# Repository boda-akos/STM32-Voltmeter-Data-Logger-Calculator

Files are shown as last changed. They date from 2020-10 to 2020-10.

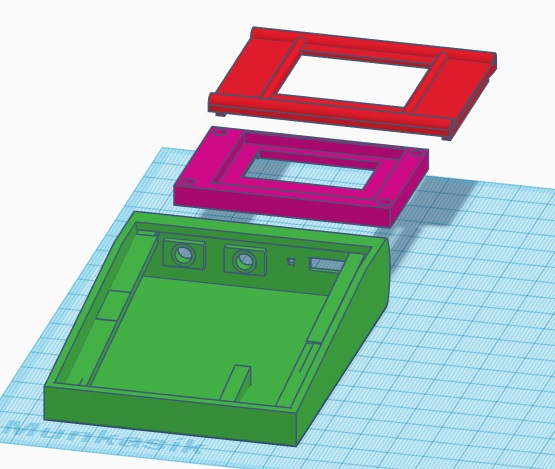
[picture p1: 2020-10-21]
3D_Parts.jpg

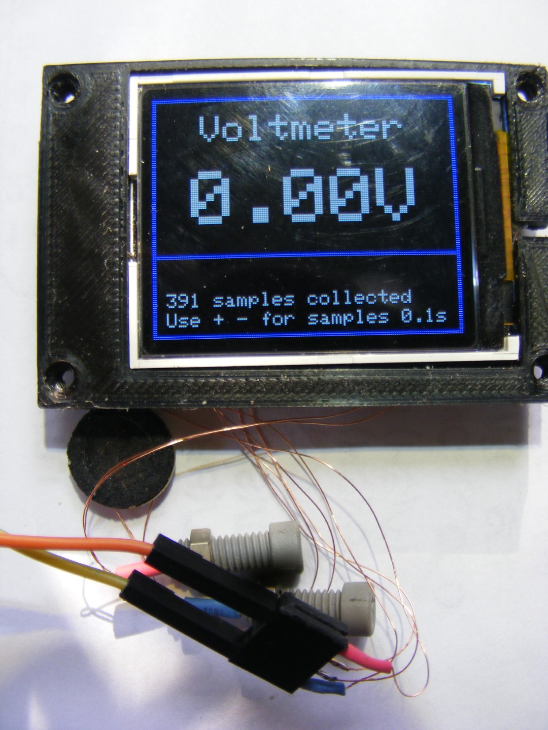
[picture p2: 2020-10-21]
DSCF2553 (Nagy).JPG

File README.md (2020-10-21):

# STM32-Voltmeter-Data-Logger-Calculator
Arduino STM32 based instrument. Voltmeter, continuity beeper, curve tracer, data logger, calculator hex and decimal.

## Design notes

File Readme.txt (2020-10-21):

Description :

This instrument has some useful functions for Arduino users. Besides being a 
voltmeter with data logging, it could answer questions like "how much voltage 
falls on the LED at 10mA current?" or "is this an IR LED or what?" by
showing the diode's voltage drop as a function of current at 5 points. It has
a beeper for continuity check as well as for logic level testing, without the 
need to look at the display. Furthermore, it can play 3 octaves "musical pitch"
as a function of voltage, which could be useful when the question arises
"is there 5V, 12V, or nothing?"  but you have to keep your eyes on the PCB.

Hex calculator 32 bits has the basic integer arithmetic functions plus AND. 
Entered hex numbers are shown at the same time in decimal in smaller numbers. 
This can be reversed so that the input is decimal and the result is decimal too
and the hex numbers are smaller.   
Operates 10-20 hours with one battery charge.

Functions : 

1. 12-bit resolution voltmeter 0-31V auto-ranging 0-3V 0-31V
   Input impedance 11.2 Mohm or more. Accuracy depends on some factors, about 1%.
    Specials : 
     - Data logging at 100ms or 1 sec intervals, max. 3600 FP data.
     - 3 octave pitch to estimate voltage without looking
     - Beep function to test logic level without looking
2. Continuity tester (1mA current)
3. Curve draw for diodes 0.1-0.3-1-3-10 mA current 0-3V voltage
4. Hex calculator, only integers, + - / * & (AND) function.
   Shows operators and results in decimal at the same time.
5. Decimal calculator, only integers. Shows HEX results as well.

Power : Li-Ion battery with USB charger.  
Dimensions : approx. 70x100x25mm.

Main parts : 
STM32 Blue Pill board 
ST7735 SPI 1.77" LCD
Micro USB Li-Ion charger PCB
Phone battery 700mAh or more
16x 6mm switch array 2 pcs 
2mm banana sockets
Off-On-On slider switch
Small (really small SMD) electronic parts
Source : Aliexpress

Circuit description : The battery is charged from micro USB by the TC4056A board. 
Voltage is fed to power switch, the 2 ON position of the switch selects calculator
or voltmeter functions. The STM32 board's regulator provides 3.3V from the battery 
3.6-4.2V. The 3.3V supply is also the reference voltage for the STM32 A/D converter.
Its value determines the accuracy, so it should be measured and entered in the code.
(float vref=3.3;  means 3.30V , enter your value if different by 1% or more) 

1. Calculator : the STM32 scans the keyboard, decodes the keys and responds to it. 
The 0-F keys work in HEX input mode, the 0-9 keys in decimal mode. & key selects 
between hex or decimal mode, C key deletes the last entry, = key shows result. 

2A. Voltmeter : This function is selected by the = key, default by start.
The instrument shows 0 for negative input voltages, but no damage is done.
The useful range is limited to approx. 31VDC. The data (3600 floating point Volts)
is stored in RAM at 1 or 0.1s intervals. 
Key functions:
 =   toggles 0.1 sec - 1 sec sample interval.
               /   turns on octave pitch. Low C 131Hz at 0V, the range is divided in 21 steps
                     so the max value corresponds to C 1044Hz 3 octaves higher.
               *   turns on logic check. Low logic level : no sound, high >0.9V level 784Hz.
               C   turns off sound 
               -   resets data log counter, fresh data starts from index = 0. 
               +   Enter data log mode, shows 50 data log, starting with recent voltage samples. 

                     In data log mode 
                                   + advances 50 samples. 
                                   - steps back 50 samples (older data).
                                   = returns to voltmeter mode, data collect resumes. 
                     Data index is shown so the user can determine when the data was collected.
                     Data collection is halted in this mode.
                
2B. Continuity tester : This function is selected by the & key.
The instrument outputs 1mA current and measures the voltage on its input. If the input < 100mV 
the beeper is activated. Higher input voltage does no harm, voltage is measured correctly.

2C. Diode curve draw : This function is selected by the # key.
Current is output in 5 logarithmic steps 0.1, 0.3, 1, 3, 10mA and the resulting input voltage 
is displayed on a graph. The values are displayed in table form too. A resistor will obviously
return a similar logarithmic voltage graph, but a diode's graph is almost linear.
Some typical values in attachment. 

Analog circuit : is built on a perfboard 45x10mm. For connections 0.25mm enamel wire is used.
The HT7333 regulator replaces the built-in RT8183-B, or AMS1117. 
The circuit is  a low-res logarithmic D/A converter driving the current output. The current 
source has 5 resistors from which 4 are switched on by Mosfets. 
The current through the resistors drives the BCV62 current mirror, the common base  is fed to PA2,
which can disable the current mirror by pulling this point high, or could measure its voltage 
to calculate the exact current flowing through the resistors. The current mirror's output is 
separated by a diode from the voltmeter input as protection against high positive voltages.

The voltage divider 10M/1.2M is connected to PA1 while a direct input is to PA0. Both are 
protected by resistors and diode network. A 100nF capacitor filters the input noise. Take care
to use this ground point for the input ground, and feed it separately to the STM32 board to 
avoid ground loop issues.
The board has a speaker driver, the 150ohm resistor controls the volume. 

Switch array : ready made 4x4 switch arrays, one cut in half. The 4 "horizontal" scan lines
are parallel connected and fed to PB9,PB6,PB4,PC13 and the 6 "vertical" scan lines are driven
by PB8,PB7,PB5,PB3,PA14,PA15. 

LCD :  1.77” LCD has FPC 14 connection.  I soldered  0.25mm enamel wire on the connector without
 difficulties.  Backlight  supply  3.3V serial 10 ohm resistor, current 35 mA.   
----------------------------------------------------------------------------
Do not attempt to measure AC voltage with this instrument, keep away from mains in particular !!

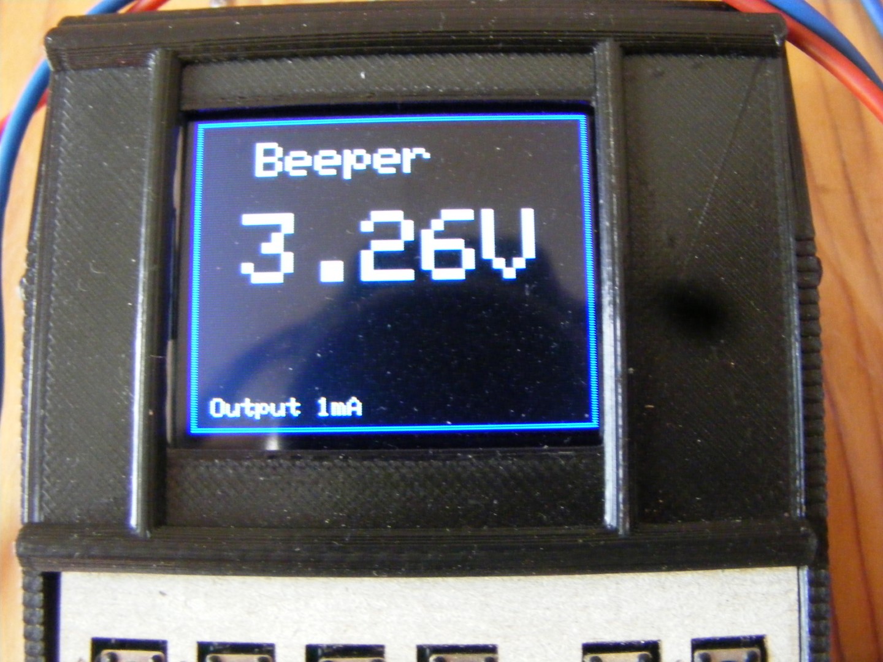
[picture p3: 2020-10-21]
DSCF2561 (Nagy).JPG

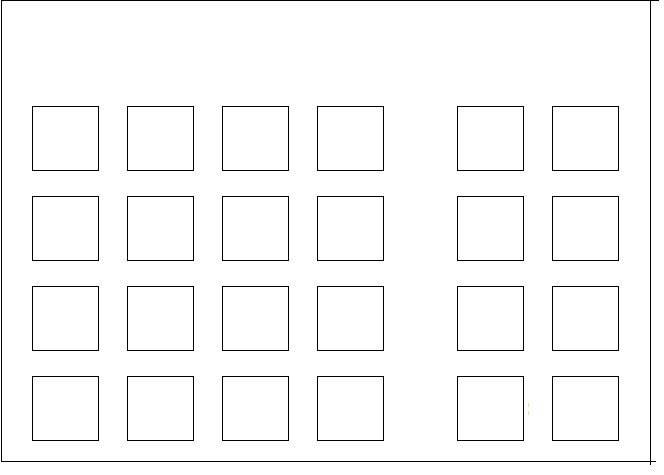
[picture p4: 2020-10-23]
hexCalcCut1.png

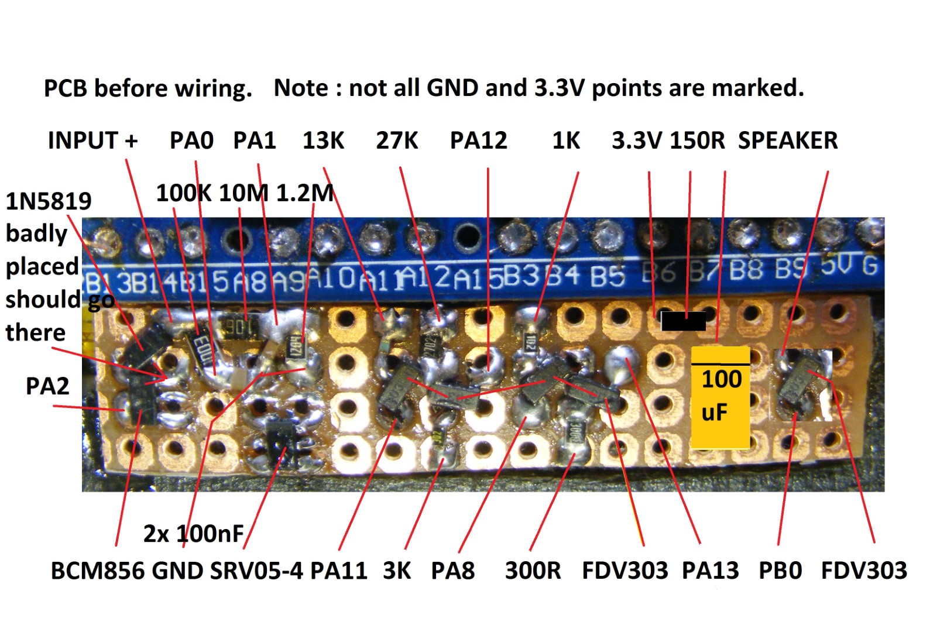
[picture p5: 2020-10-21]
PCB (Nagy).jpg

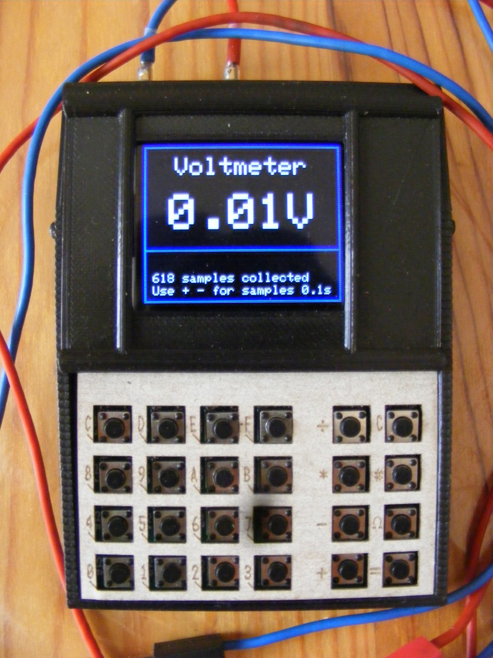
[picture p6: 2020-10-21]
DSCF2554 (Nagy).JPG

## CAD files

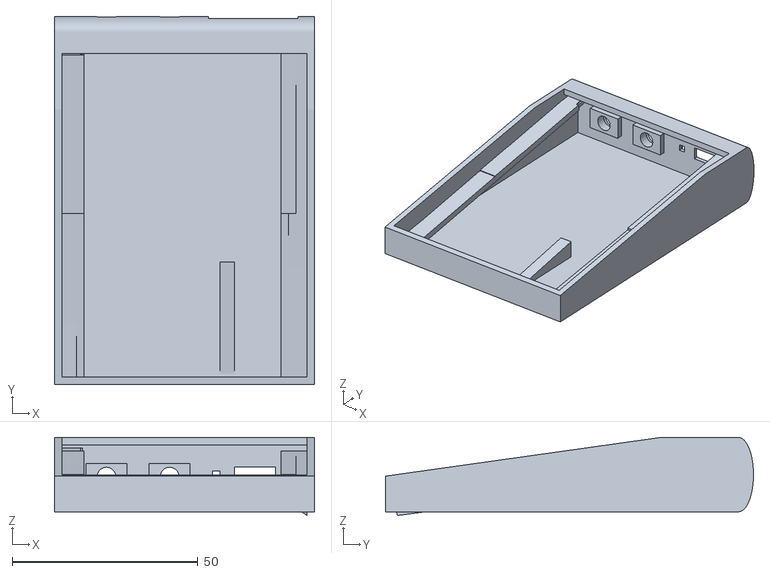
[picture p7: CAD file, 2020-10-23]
HexCalcBase.stl
70.0 x 99.0 x 21.0

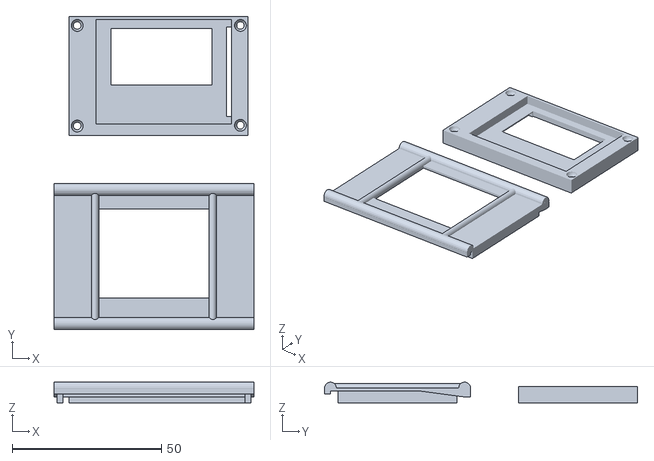
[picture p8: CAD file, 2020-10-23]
HexCalcTop.stl
67.0 x 105.0 x 7.00

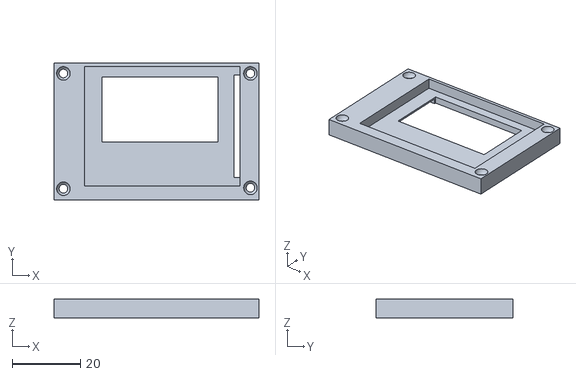
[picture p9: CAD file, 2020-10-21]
Frame.stl
60.0 x 40.0 x 5.50

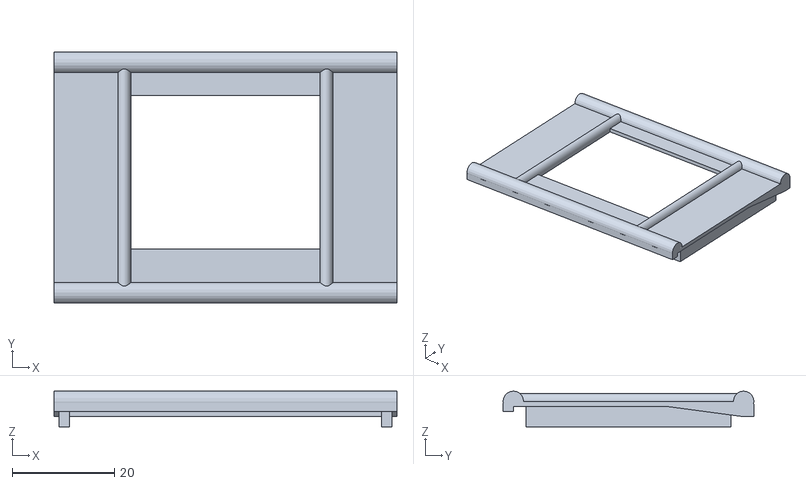
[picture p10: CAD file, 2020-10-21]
Top.stl
67.0 x 49.0 x 7.00

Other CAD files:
Base.stl

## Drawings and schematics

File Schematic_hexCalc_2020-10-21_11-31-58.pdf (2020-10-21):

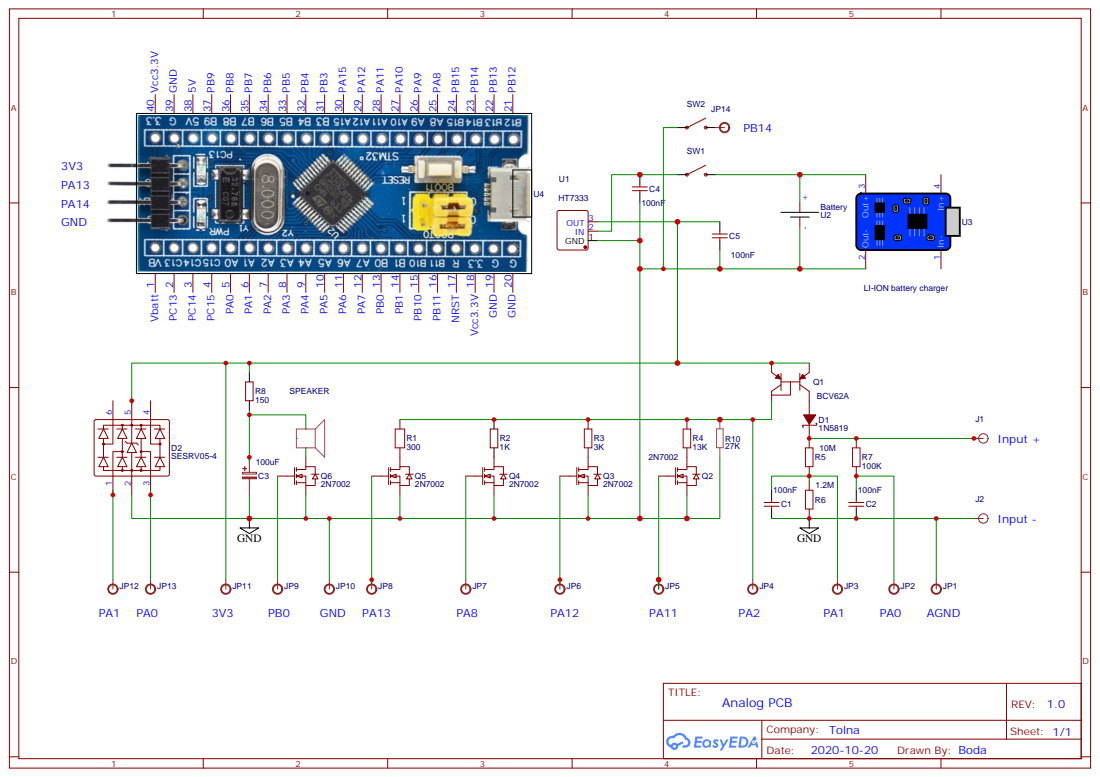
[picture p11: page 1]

LI-ION battery charger

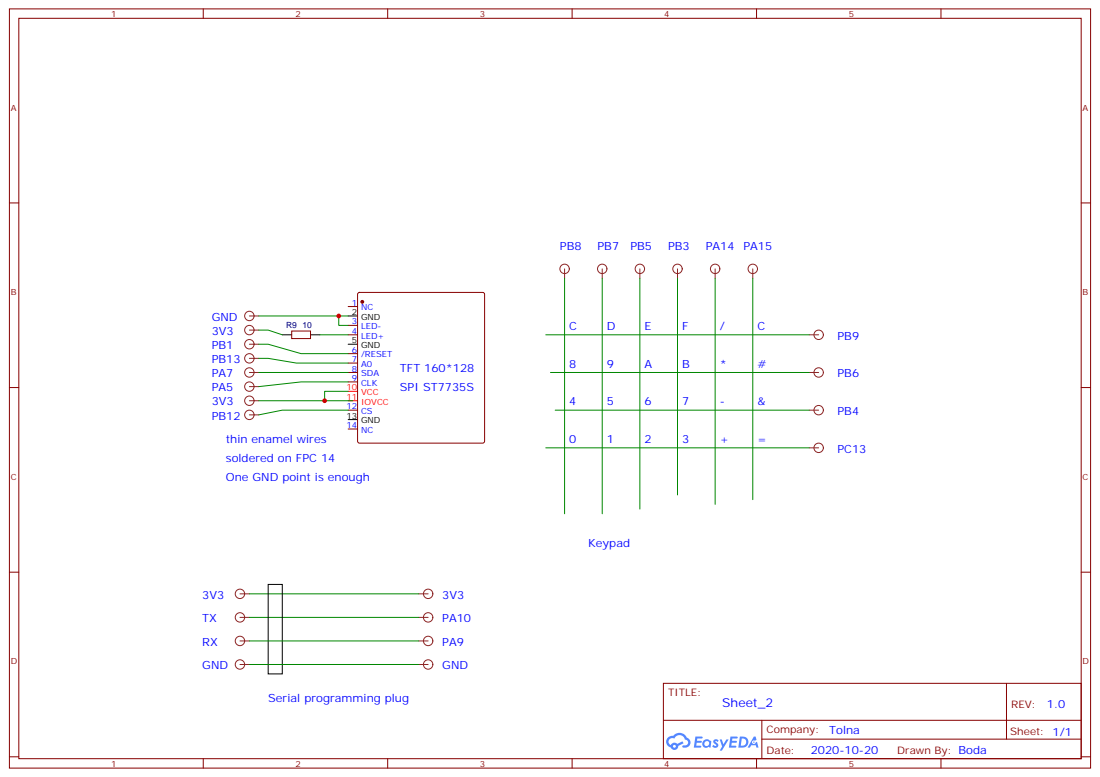
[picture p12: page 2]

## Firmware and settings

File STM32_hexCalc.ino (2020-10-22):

//STM32F103CBT6 (china copy GD103) ST7735 14 pin SPI 1.77" 
//PA0 0-3300mV 100k series, 100nF to GND. PA1 divider 10M / 1M2, 100nF to GND 
//PA2 connected to current mirror common base. when input, samples the ref V on resistors. When high output, disables the current mirror.
//100uA flows always (27.4k). PA11 200uA,PA12 900uA,PA8 2.9mA,PA13 9.9mA via mosfets
//PB14 senses power switch position

#include <Adafruit_GFX.h>  
#include <Adafruit_ST7735.h> 
#include <SPI.h>

#define TFT_CS     PB12
#define TFT_DC     PB13
#define TFT_RST    PC14 

Adafruit_ST7735 tft = Adafruit_ST7735(TFT_CS, TFT_DC, TFT_RST);

byte kdrv[]={PB8,PB7,PB5,PB3,PA14,PA15};
byte kbin[]={PB9,PB6,PB4,PC13};
byte uasw[]={PA11,PA12,PA8,PA13};
byte kbcod[]={12,8,4,0,13,9,5,1,14,10,6,2,15,11,7,3,'/','*','-','+','C','&','#','='};
float sample[3600],prev[8],vref=3.300,m ;   //vref is the 3.3V supply HT7333 measured w Fluke12;
unsigned int tim1,tim2,tim3,tim4=100,timout=6000;
byte scn=0xff, stat ,opr, hexopr=1,dvm =0; String txt[]={"DEC","HEX"};
String mA[]={"0.1m","0.3m","1.0m","3.0m","10mA"};
unsigned int op[2],num,sidx,tidx,nidx; // sample , tft index 

int fr, freq[]={261,293,330,349,392,440,494}; //261,277,293,311,330,349,367,392,415,440,466,494}; //c c# d d# e f f# g g# a a# b c c# d d# e f f# g g# a a# b
byte x;
void setup(void) {
  disableDebugPorts();
  Serial.begin(9600);
  tft.initR(INITR_BLACKTAB); 
  tft.setRotation(1);
  tft.setTextColor(ST7735_WHITE,ST7735_BLACK);
  for (byte i=0; i<6; i++) pinMode(kdrv[i],OUTPUT); 
  for (byte i=0; i<4; i++) pinMode(kbin[i],INPUT_PULLUP);
  pinMode(PB14,INPUT_PULLUP);  //power switch position
  for (byte i=0; i<4; i++) pinMode(uasw[i],OUTPUT);
  pinMode(PA2,OUTPUT); digitalWrite(PA2,HIGH);tft.fillScreen(ST7735_BLACK); 
  pinMode(PA0, INPUT_ANALOG); pinMode(PA1, INPUT_ANALOG);
  
  //tft.fillScreen(ST7735_BLACK); 
    Timer4.setPeriod(32000); Timer4.setPrescaleFactor(100);
    Timer4.setMode(TIMER_CH1,TIMER_OUTPUTCOMPARE);
    Timer4.setCompare(TIMER_CH1, 1); 
    Timer4.attachInterrupt(TIMER_CH1,handler);
    Timer4.refresh();
    //Timer4.resume();
    Timer4.pause();
    //pinMode(PA9, OUTPUT);
  pinMode(PB0, PWM);  //sound output Timer3
  Timer3.setPrescaleFactor(1000);    //72Mhz divider 
  Timer3.pause(); if (digitalRead(PB14)) dvmFrame(61); else calFrame(); 
}

void loop() {
  if (digitalRead(PB14) !=dvm) {if ( digitalRead(PB14))dvmFrame(61); else calFrame(); };
dvm=digitalRead(PB14);
if (dvm) {                 // stat 0x00-0x0f dvm ; 0x10-0x1f beeper ; 0x20-0x2f scanner
if (scn !=0xff) { byte r=kbcod[scan()]; 
                     
                    if (r==61) {dvmFrame(r);stat = 0x00; if (tim4 == 100) tim4=1000; else tim4=100; } //voltmeter
                    if (r==35) {dvmFrame(r);stat = 0x10;} //beeper
                    if (r==38) {dvmFrame(r);stat = 0x20;} //scanner
                    if (r==42) {stat |= 0x02; stat &=~0x04; Timer3.resume(); tim1 = millis()+timout;} //sound on logic
                    if (r==47) {stat |= 0x04; stat &=~0x02; Timer3.resume(); tim1 = millis()+timout;} //sound on offset
                    if (r==67) {stat &= ~0x06; Timer3.pause();} //sound off
                    if (r=='+') {if (stat&0x08) {stat &= ~0x08;tft.setCursor(8,90); tft.fillRect(7,90,115,30,ST7735_BLACK);}
                                else stat |= 0x08; nidx=sidx;}
                    if (r=='-') {sidx =0; }
                    
                    while(scan() != 0xff); }

                      
if ((stat & 0xf0) == 0x00) { //============================ Voltmeter ================================
 
   pinMode(PA2,OUTPUT); digitalWrite(PA2,HIGH); tft.setCursor(10,45); m= analogRead(PA0);
  if (m>4090) {stat |=0x01; tim2=millis()+timout;} else if (millis()> tim2) stat &= ~0x01;
  if (tim2>millis()) {m=analogRead(PA1); m *= 11.2; m /=1.2;} 
  m*= vref; m/=4095; tft.setCursor(20,40);tft.setTextSize(4); tft.print(m); tft.print('V'); 
  tft.drawLine(2,85,157,85,ST7735_BLUE);tft.drawLine(2,84,157,84,ST7735_BLUE);
  tft.setCursor(8,94); tft.setTextSize(1);
  if (stat & 0x04) tft.print("Sound on    "); else 
  if (stat & 0x02) tft.print("Sound > 0.9V"); else 
  if (!(stat & 0x06)) tft.print("            ");
  tft.setCursor(7,104); tft.print(sidx); tft.print(" samples collected   ");
  tft.setCursor(7,114); tft.print("Use + - for samples ");
  tft.print((float)tim4/1000,1);tft.print('s');//tft.print(stat);
  if (stat & 0x06) sound(); if (millis()>tim1) { Timer3.pause(); }
  if (m>0.2 && stat&0x06) {tim1  = millis()+ timout; Timer3.resume();}  //cycle = 31ms
  if (millis() > tim3) {tim3= tim4 * ((millis()/tim4)+1); //=======================tim4 loop 100ms,1s
  if (stat & 0x08) { 
  dvmFrame('+'); tft.print((float)tim4/1000,1); tft.print(" sec");
  while  (scan() != 23  ) { //wait for = sign
  if (nidx<50) nidx=50; tft.setCursor(6,22);
  for (byte i=50; i; i--) {tft.print(sample[nidx-i]); if ((i%5)==1) tft.println(); tft.print(' ');}
  tft.drawLine(0,0,0,120,ST7735_BLUE);tft.drawLine(1,0,1,120,ST7735_BLUE);
  tft.setCursor(6,115); tft.print("Samples "); tft.print(nidx-50); tft.print(" to ");tft.print(nidx-1); tft.print("   ");
     //while(scan() != 18 && scan() !=19) {if (scan() == 23) break;}
  while(scan() != 18 && scan() !=19 && scan() !=23 );  //react to + - = only
  if (scan() ==18 && nidx>50) nidx -=50;  if (scan() == 19 ) nidx +=50; if (nidx > 3600) nidx=3600;
   
  } //show table inner loop
  } //Table show exit, 0x08 flag reset when calling voltmeter menu
  
  sample[sidx]=m; sidx++; 
  if (sidx > 3599) sidx=0;
  }  //tim4 loop 100ms,1s  //Serial.println(millis()-tim2); Serial.print(' '); tim2=millis();
  }
  
if ((stat & 0xf0) == 0x10) { //=========================== Beeper ====================================
       float m; pinMode(PA2,INPUT); digitalWrite(PA12,1); 
       if (analogRead(0)> 4090) {m= analogRead(PA1); m *= 11.2; m /=1.2;} else m= analogRead(PA0); 
       m*= vref; m/=4095; 
       tft.setCursor(20,40);tft.setTextSize(4); tft.print(m); tft.print('V');
       if ( m < 0.1 ) {Timer3.resume(); sound();} else Timer3.pause(); 
       
  }
                     
if ((stat & 0xf0) == 0x20) {//============================ Scanner ===================================
 Timer3.pause();
  pinMode(PA0,OUTPUT); digitalWrite(PA0,0); uamp(0); delay(100); pinMode(PA0,INPUT); //discharge input
  for (byte i=0; i<5; i++) {uamp(1+i);  
             for  (byte i=0; i<10; i++) {delay(10); scn= scan(); if (scn !=0xff) break;}
             sample[i]= analogRead(PA0);  //delay and scan keyboard
             sample[i] = analogRead(PA0); sample[i] *= vref; sample[i]/=4095;}//graph
  tft.drawRect(0,0,159,127,ST7735_BLUE);tft.drawRect(1,1,157,125,ST7735_BLUE);
  tft.setTextSize(1); tft.setCursor(80,35); tft.print("mA-V  Graph");
  byte a=10; 
  for (byte i=0; i<5; i++) {
    tft.fillCircle( i*a+15,125-prev[i]*40,3,ST7735_BLACK); prev[i]=sample[i];
    if (sample[i]<3.1) tft.fillCircle( i*a+15,125-sample[i]*40,3,ST7735_WHITE);
    tft.setCursor(80,110-i*14); tft.print(mA[i]);tft.print("  ");tft.print(sample[i],2);tft.print("V");
    
  }
 
  for (byte i=0; i<3; i++) for (byte j=0; j<56; j++) if (j % 4) tft.drawPixel(j, i*40+5 ,ST7735_BLUE); 
  for (byte i=0; i<3; i++) { tft.setCursor(3, 113-i*40); tft.print(i);   }
  for (byte i=0; i<10; i++) {delay(50); scn= scan(); if (scn !=0xff) break;}  
  }
}

else 
{  //===================================== Calculator ===============================
scn=scan();
//if (scn !=0xff) {if (scn<0x10) Serial.println(kbcod[scn],HEX); else Serial.write(kbcod[scn]);}
if (scn !=0xff) {  //stat = 0 enter 1st operand; stat = 1 have operator; stat = 2 calc result
  
  
  if (scn<0x10) {  //=========================== it is a number ===========================
  tft.setCursor(10, 10+30*stat); 
  if (hexopr) { op[stat] = op[stat]*16; op[stat] +=kbcod[scn]; tft.print(op[stat],HEX);}
         else { if (kbcod[scn]<0x0A) {op[stat] = op[stat]*10; op[stat] +=kbcod[scn];} tft.print(op[stat],DEC);} 
  tft.setCursor(100, 15+30*stat);tft.setTextSize(1);
  if (hexopr) tft.print(op[stat],DEC); else tft.print(op[stat],HEX);
  tft.setTextSize(3);}  //It is a (hex,dec) number
  //============================== it is an operator ================================
  else { tft.setCursor(138, 10+ 30*stat); 
    // 
    tft.write(kbcod[scn]); stat++;
    
    if (kbcod[scn]=='#')  {hexopr = 1-hexopr; calFrame();}
    
    //========================== CE ==========================================
    if (kbcod[scn]=='C')  {  stat--; 
    op[stat] /=(10+6*hexopr);
    delay(200); //Serial.print(op[0],HEX);Serial.print(" "); Serial.print(op[1],HEX);Serial.print(" ");Serial.write(opr);Serial.println(" ");
   tft.fillRect(10,10,159-12,90,ST7735_BLACK);
   
   if (stat ==0) { //tft.setTextColor(ST7735_RED,ST7735_BLACK);
   tft.setCursor(10, 10+30*stat); 
   if (hexopr) {  tft.print(op[stat],HEX);}
         else {  tft.print(op[stat],DEC);} 
  tft.setCursor(100, 15+30*stat);tft.setTextSize(1);
  if (hexopr) tft.print(op[stat],DEC); else tft.print(op[stat],HEX);
  tft.setTextSize(3);//tft.setTextColor(ST7735_WHITE,ST7735_BLACK);
   } //stat0
   
     if (stat ==1) { //tft.setTextColor(ST7735_RED,ST7735_BLACK);
   tft.setCursor(10, 10);
   if (hexopr) { tft.print(op[0],HEX);}  else { tft.print(op[0],DEC);}
         tft.setCursor(140, 10); tft.write(opr); 
   tft.setCursor(100, 15);tft.setTextSize(1);
   if (hexopr) tft.print(op[0],DEC); else tft.print(op[0],HEX);
   tft.setTextSize(3);
   tft.setCursor(10, 10+30*stat);
   if (hexopr) {  tft.print(op[stat],HEX);}
         else {  tft.print(op[stat],DEC);} 
  
  tft.setCursor(100, 15+30*stat);tft.setTextSize(1);
  if (hexopr) tft.print(op[stat],DEC); else tft.print(op[stat],HEX);
  tft.setTextSize(3);//tft.setTextColor(ST7735_WHITE,ST7735_BLACK);
   }  //stat1
   
   }  //CE clear last entry

   //================================ CE end ========================
   //delay(50); Serial.print(op[0],HEX);Serial.print(" "); Serial.print(op[1],HEX);Serial.print(" ");Serial.write(opr);Serial.println("... ");
   if (stat == 1 && kbcod[scn] !='C') opr = kbcod[scn];
   if (stat>0  && kbcod[scn]=='=') { // result , clear
    switch (opr) { 
                    case '+' : num = op[0] + op[1]; break;
                    case '-' : num = op[0] - op[1]; break;
                    case '*' : num = op[0] * op[1]; break; 
                    case '/' : num = op[0] / op[1]; break;
                    case '&' : num = op[0] & op[1]; break;
                    case '=' : num = op[0]        ; break;
      }
   //if (opr == '+') num = op[0] + op[1]; if (opr == '-') num = op[0] - op[1]; if (opr == '*') num = op[0] * op[1]; if (opr == '/') num = op[0] / op[1]; 
   
    tft.setCursor(10, 10+ 30*stat);
    if (hexopr) tft.print(num,HEX); else tft.print(num,DEC);
    tft.setCursor(90, 40+30*stat);tft.setTextSize(1);
   if (hexopr) tft.print(num,DEC); else tft.print(num,HEX);
   tft.setTextSize(3);
    while (scan() != 0xff); delay(100);
    while (scan() == 0xff); delay(100);
    calFrame();
   } //stat2
  }  //not a number
  }

while(scan() != 0xff); delay(50);
} //not dvm

 for  (byte i=0; i<10; i++) {
 if (stat & 0xf0) delay(5); //voltmeter = no delay
 scn= scan(); if (scn !=0xff) break;}
} //loop

void handler (void)
  {
  digitalWrite(PA9,!digitalRead(PA9));

  byte sc =kbcod[scan()];
 }

byte dlyScan(unsigned int d){
     byte dsc; 
     while(d--) {delay(1); dsc=scan(); }
     return(dsc);
}

byte scan(void){
  byte i,j,r=0xff;
  for (i=0; i<6; i++) {digitalWrite(kdrv[i],LOW); for (j=0; j<4; j++) if (digitalRead(kbin[j])==0) r=i*4+j; digitalWrite(kdrv[i],HIGH);}
  return(r);
  }
  
void dvmFrame(byte x){tft.fillScreen(ST7735_BLACK); tft.drawRect(0,0,159,127,ST7735_BLUE);tft.drawRect(1,1,157,125,ST7735_BLUE);
                tft.setTextSize(2); tft.setCursor(25,10); 
                switch (x) {
                 case 61: { tft.print("Voltmeter"); break;}
                 case 35: { tft.print("Beeper"); tft.setTextSize(1);tft.setCursor(8,114); tft.print("Output 1mA"); break; }
                 case 38: { tft.setCursor(70,10); tft.print("Scanner"); break; } 
                 case '+': {tft.setTextSize(1);tft.print("Samples "); break;}
      }               
  }
  
void calFrame(void) {
  tft.fillScreen(ST7735_BLACK); tft.setCursor(10,10); tft.setTextSize(3);tft.print(0);
  tft.drawRect(0,0,159,127,ST7735_BLUE);tft.drawRect(1,1,157,125,ST7735_BLUE);
  stat=0; op[0]=op[1]=0; num=0; opr=0;
  tft.setCursor(10,100); tft.setTextSize(2);tft.print(txt[hexopr]);tft.setTextSize(1);
  tft.setCursor(90,112); tft.print(txt[1-hexopr]);tft.setTextSize(3);
  }

  void uamp(byte u){
    //0=0, 1=100uA, 2=300uA, 3=1mA, 4=3mA, 5=10mA values
    if (u>5) u=5; if (u) pinMode(PA2,INPUT);
    for (byte i=0; i<4; i++) digitalWrite(uasw[i],0);
    switch (u) {
              case 0: { pinMode(PA2,OUTPUT); digitalWrite(PA2,HIGH); break;}
              case 1: { break; }
              default:{ digitalWrite(uasw[u-2],1); break; } //2 to 5 will be 0 to 3
      }
    }

void sound(void){
   
    int dcval=analogRead(PA1); dcval/=186; //31V range, 3 octaves, 22 pitch
    if ((stat & 0x04)) {
    if (dcval>21) dcval=21; 
    if (dcval < 7) fr=freq[dcval]/2;                    //low octave
    if (dcval > 6 && dcval < 14) fr=freq[dcval % 7];    //mid
    if (dcval > 13 && dcval < 21) fr=freq[dcval % 7]*2; //high
    if (dcval > 20) fr=freq[dcval % 7]*4;               //over
    }
    if (stat & 0x02){ if (dcval>5) fr=freq[4]*2; else fr=20000;}
    if ((stat & 0xf0) == 0x10) fr=freq[4]*2;
    fr= 9680*4/fr;
    Timer3.setOverflow(fr);  //timer overflow frequency
    pwmWrite(PB0,fr / 2);    //PWM 50%
  }    
    
 
